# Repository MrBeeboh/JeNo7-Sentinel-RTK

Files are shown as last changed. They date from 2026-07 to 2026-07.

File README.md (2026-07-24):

# JeNo 7" + Sentinel RTK (work in progress)

Open packaging work to run an **F450 Sentinel–class RTK / ArduPilot / Walksnail** avionics stack on a **[JeNo 7"](https://github.com/WE-are-FPV/JeNo-7)** long-range FPV frame.

This repo is **not** a finished airframe release. It is shared so others can reuse the **editable CAD pack**, the **Sentinel-on-JeNo layout plan**, and contribute mounts (GNSS roof, Walksnail dual plates, TPU).

---

## What’s in here

| Path | Contents |
|---|---|
| **`Sentinel-on-JeNo7/`** | Design plan: how Sentinel gear maps onto JeNo (UM980, Q39, Walksnail dual, LR900, RP3, stack) |
| **`Editable/`** | Split CAD for FreeCAD / Fusion / AutoCAD LT — one part per file where possible |
| **`JeNo-7-main/`** | Upstream JeNo 7" v1.1.1 sources (frame DXF/STEP/STL + official TPU) |

### Editable CAD pack (start here for redesign)

- `Editable/01-CARBON-3D/` — individual plate/arm **STEP** + **FCStd** (Fusion / FreeCAD)
- `Editable/02-CARBON-2D-DXF/` — per-plate **DXF** for CNC / AutoCAD LT (English layers: CUT, POCKET, …)
- `Editable/00-MASTER/` — full assembly STEP from the official export
- `Editable/README.md` — which tool opens what
- `Editable/FREECAD-HOWTO.md` — FreeCAD notes (imported solids are not parametric history)

### Sentinel packaging plan

- `Sentinel-on-JeNo7/DESIGN.md` — plain-language fit plan, what stock JeNo covers, what must be redesigned (GNSS roof, camera plates, sensors, 7" motors)

---

## License and attribution

### Upstream JeNo 7"

Frame and official TPU files in `JeNo-7-main/` are **[CC BY 4.0](https://creativecommons.org/licenses/by/4.0/)** by **WE are FPV / JeNo** (nochamo and community).  

Upstream project: [github.com/WE-are-FPV/JeNo-7](https://github.com/WE-are-FPV/JeNo-7)

If you redistribute or remix JeNo geometry, **credit WE are FPV / JeNo** and keep the license notice.

### This repository’s additions

Layout docs, split CAD packaging scripts, and Sentinel integration notes are provided for the community. When in doubt, treat remixes of JeNo geometry as still under **CC BY 4.0** with attribution to the original authors.

---

## Not included (on purpose)

- `JeNo-7-main.zip` — duplicate of the extracted tree  
- `Editable/03-TPU-3D/from-STL-mesh/` — huge mesh-derived STEP files; use official STLs under `JeNo-7-main/02-TPU/` instead  

---

## Related projects

- **JeNo 7" upstream:** https://github.com/WE-are-FPV/JeNo-7  
- **F450 Sentinel** (avionics / RTK source of truth for this build) lives in the builder’s local `F450-Sentinel` tree and is not fully mirrored here yet  

---

## Status

| Item | Status |
|---|---|
| Official JeNo files | Vendored v1.1.1 |
| Split editable CAD | Done (carbon + DXF + partial TPU solids) |
| Sentinel-on-JeNo design plan | Draft in `Sentinel-on-JeNo7/DESIGN.md` |
| GNSS roof plate CAD | **Not designed yet** |
| Walksnail dual camera plates | **Not designed yet** |
| Built / flown 7" Sentinel | **Not yet** |

Contributions welcome: roof plate DXF/STEP, Walksnail dual plates, TPU mounts, BOM for 7" motors/props with this stack.

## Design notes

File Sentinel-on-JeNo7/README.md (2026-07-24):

# Sentinel on JeNo 7"

Goal: fly the **F450 Sentinel** avionics and RTK mission on a **JeNo 7"** frame.

**Start here:** [DESIGN.md](DESIGN.md)

## Design files

| File | Type | What |
|---|---|---|
| `GNSS_Roof_Plate.scad` | OpenSCAD source | GNSS roof plate (parametrized) |
| `GNSS_Roof_Plate_fc.dxf` | DXF | **Use this for CNC cutting** — 14 circle holes + polyline outline |

**Note on OpenSCAD exports:** This system has OpenSCAD 2021.01 which has a buggy binary STL writer. Always use `--export-format asciistl` when exporting STL from the .scad files. The FreeCAD-generated files (`_fc.*`) are the production reference.
| `GNSS_Roof_Plate_fc.step` | STEP | 3D solid for Fusion/FreeCAD |
| `GNSS_Roof_Plate_fc.stl` | STL | 3D print for test fit |
| `TPU_Mounts.scad` | OpenSCAD source | Parametric LR900/RP3/CV50 mounts |
| `LR900_Mount.stl` | STL | TPU cradle for MicoAir LR900-P |
| `RP3_Mount.stl` | STL | TPU cradle for RadioMaster RP3 V2 |
| `CV50_Mount.stl` | STL | Nadir bracket for CV50 rangefinder |

## Related paths

- Frame CAD pack: `../JeNo-7-main/01-FRAME/`
- Official JeNo files: `../JeNo-7-main/`
- Sentinel electronics source of truth:  
  `../../F450-Sentinel/Current design folder/`

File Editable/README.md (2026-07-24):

# JeNo 7" — Editable CAD pack

Converted from the official open-source **JeNo 7 v1.1.1** export so you can open **one part at a time** in FreeCAD, Fusion 360, or AutoCAD LT.

**License:** CC BY 4.0 (credit WE are FPV / JeNo authors).  
**Source:** `../JeNo-7-main/` (unchanged originals).

---

## Which tool should I use?

| Goal | Best tool | Open these |
|---|---|---|
| Edit a carbon plate 3D (holes, outline, thickness) | **Fusion** or **FreeCAD** | `01-CARBON-3D/*.step` |
| Send carbon to CNC / edit 2D cut paths | **AutoCAD LT** (or Fusion sketch) | `02-CARBON-2D-DXF/` |
| Edit TPU print parts | **FreeCAD** or **Fusion** | `03-TPU-3D/from-assembly-STEP/` first; full kit in `from-STL-mesh/` |
| Print TPU as-is (no edit) | Slicer | original `../JeNo-7-main/02-TPU/*.stl` |
| See whole assembled frame | FreeCAD / Fusion | `00-MASTER/JeNo7_Assembly_from_STEP.step` |

**Recommended workflow for most changes**

1. **Fusion (other PC):** File → Open → pick a single `01-CARBON-3D/*.step`  
2. Right‑click body → **Convert** / work in **Parametric** design (or capture design history if offered)  
3. Edit, then export STEP (for FreeCAD) and DXF (for CNC)  

or

1. **FreeCAD:** File → Open → `01-CARBON-3D/Bottom_plate_3mm.FCStd` (or `.step`)  
2. Use **Part Design** / **Part** to cut holes, pad, boolean  
3. Export STEP / TechDraw DXF when done  

or

1. **AutoCAD LT:** open a file under `02-CARBON-2D-DXF/from-all-versions-dxf/`  
2. Layers: `CUT`, `POCKET`, `CHAMFER`, `COUNTERSINK`  
3. Edit polylines → save DXF for the CNC shop  

---

## Folder map

```
Editable/
├── README.md                          ← this file
├── 00-MASTER/
│   ├── JeNo7_Assembly_from_STEP.step  ← full assembly (one config)
│   ├── JeNo7_Assembly_from_STEP.FCStd
│   └── PARTS_MANIFEST.txt
├── 01-CARBON-3D/                      ← BEST for Fusion + FreeCAD
│   ├── Arm_8mm.step / .FCStd
│   ├── Arm_key.step / .FCStd
│   ├── Bottom_plate_3mm.step / .FCStd
│   ├── Middle_plate_2p5mm.step / .FCStd
│   ├── Top_plate_2p5mm.step / .FCStd
│   └── Camera_plate_25deg_O4.step / .FCStd
├── 02-CARBON-2D-DXF/
│   ├── from-all-versions-dxf/         ← BEST for AutoCAD LT (all options)
│   │   ├── 00_ALL_VERSIONS_English_layers.dxf
│   │   ├── Bottom_plate_variant_*.dxf
│   │   ├── Top_plate_variant_*.dxf
│   │   ├── Middle_plate_variant_*.dxf
│   │   ├── Camera_plate_variant_*.dxf
│   │   ├── Arm_or_reinforcement_*.dxf
│   │   └── PART_INDEX.txt
│   └── from-step-projection/          ← 2D of the STEP config only
├── 03-TPU-3D/                         ← TPU / print parts
│   ├── from-assembly-STEP/            ← cleaner BREP solids (prefer for edit)
│   └── from-STL-mesh/                 ← full kit from official STLs (heavy meshes)
├── 04-HARDWARE-REF/                   ← standoff reference solids
└── scripts/                           ← re-run converters if needed
```

---

## Important limitations (so you don’t fight the tools)

1. **These are not parametric native Fusion/SolidWorks projects.**  
   They are **BREP solids** (STEP) and **2D polylines** (DXF) reverse-exported from the official cut files. You can edit them freely, but there is **no design history** (no sketch tree from the original author).

2. **The STEP assembly is one configuration only**  
   (8 mm arms + top/bottom “04” + 25° O4 camera plates + some TPU).  
   **All carbon options** (Classic/Light/Bando, 6 mm arms, other cam plates) live in the **DXF pack** under `from-all-versions-dxf/`.

3. **TPU from STLs** (`JeNo7_*.step`) can be heavy mesh-based solids. Prefer:
   - `TPU_Rear_bumper.step`, `TPU_Antenna_*.step` from the assembly when present  
   - or re-model from the STL as a size reference  

4. **CC BY 4.0:** if you publish a remix, credit JeNo / WE are FPV.

---

## Quick start by app

### Fusion 360 (Windows PC)

1. Copy `01-CARBON-3D/` (and optionally `03-TPU-3D/TPU_*.step`) to the other PC.  
2. **Insert → Insert Mesh** is **not** what you want. Use **File → Open** on the `.step`.  
3. If Fusion asks to capture design history: **yes** if you want timeline features.  
4. For CNC: create a sketch from the face → **DXF export**, or use the ready DXFs in `02-CARBON-2D-DXF/`.

### FreeCAD (this machine)

AppImage: `~/Applications/FreeCAD_1.1.1-Linux-x86_64-py311.AppImage`

```text
File → Open → Editable/01-CARBON-3D/Bottom_plate_3mm.FCStd
```

Or open the assembly:

```text
Editable/00-MASTER/JeNo7_Assembly_from_STEP.FCStd
```

Each body is a separate `Part::Feature` you can toggle visible and edit.

### AutoCAD LT

Open either:

- **One plate:** `02-CARBON-2D-DXF/from-all-versions-dxf/Bottom_plate_variant_01.dxf`  
- **Whole sheet, English layers:** `00_ALL_VERSIONS_English_layers.dxf`

Layer meanings:

| Layer | Meaning |
|---|---|
| `CUT` | Outer profile / through cuts |
| `POCKET` | Pockets (partial depth) |
| `CHAMFER` | Chamfers |
| `COUNTERSINK` | Countersinks |
| `ANNOTATION` | Labels (not cut) |

See `PART_INDEX.txt` for sizes of each split plate.

---

## Re-generate this pack

If you update the upstream JeNo zip:

```bash
# 1) Split STEP → per-part STEP/FCStd (FreeCAD)
~/Applications/FreeCAD_1.1.1-Linux-x86_64-py311.AppImage -c \
  "import runpy; runpy.run_path(r'.../Editable/scripts/01_split_step_to_parts.py', run_name='__main__')"

# 2) Split ALL_VERSIONS DXF for ACAD LT
python3 ".../Editable/scripts/02_split_dxf_all_versions.py"

# 3) Project carbon STEP → DXF
~/Applications/FreeCAD_1.1.1-Linux-x86_64-py311.AppImage -c \
  "import runpy; runpy.run_path(r'.../Editable/scripts/03_project_carbon_to_dxf.py', run_name='__main__')"
```

---

## What to open first (suggested)

| If you want to… | Open |
|---|---|
| Lengthen the body / move stack holes | `01-CARBON-3D/Bottom_plate_3mm.step` + `Middle_plate_2p5mm.step` + `Top_plate_2p5mm.step` |
| Change motor spacing | `01-CARBON-3D/Arm_8mm.step` |
| Change camera angle / O3 vs O4 plate | DXF `Camera_plate_variant_*.dxf` (all options) or STEP `Camera_plate_25deg_O4.step` |
| Print TPU bumper | `03-TPU-3D/TPU_Rear_bumper.step` or `JeNo7_Back_Bumper.step` |

Original untouched sources remain in `../JeNo-7-main/`.

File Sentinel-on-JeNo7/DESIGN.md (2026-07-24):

# Sentinel on JeNo 7" — Design plan

**What this is:** A plan to move the **F450 Sentinel electronics and mission** (RTK rover, Walksnail dual, ArduPilot stack, radios) onto a **JeNo 7"** carbon frame, and to list what must be redesigned so you can reshape plates and mounts freely later.

**What this is not:** A finished CAD package yet. You asked to modify parts so everything fits — this document is the map of *what* has to change and *where* each Sentinel piece goes, so CAD work has a target instead of guesswork.

**Source of truth for electronics:**  
`Documents/DRONE Builds/F450-Sentinel/Current design folder/`  
especially `README.md`, `Stack_and_Wiring.md`, `ArduPilot_Configuration.md`.

**Source of truth for frame geometry:**  
`Documents/DRONE Builds/custom 7 inch frame/Editable/`  
and official `JeNo-7-main/`.

---

## 1. Goal in one paragraph

You want one aircraft that flies as a **7" long-range / freeride FPV platform** (JeNo) but carries the **Sentinel payload**: ArduPilot H743 stack, Walksnail Avatar HD Pro Dual, UM980 + Waveshare Q39 helix, UBEC for the GNSS, LR900 telemetry (RTCM path), RP3 ELRS, and the optical flow / rangefinder path you already run on the F450. The ground base station (second UM980 + LicheeRV Nano) stays on the ground — it does not move onto the airframe.

---

## 2. Assumptions (top three)

If any of these is wrong, say so and we adjust the plan.

1. **You are transplanting the Sentinel *avionics and wiring philosophy*, not the F450 airframe as a whole.** The F450’s 10" props and A2212 motors do **not** bolt onto JeNo 7" arms. The 7" needs its own motors and props (typically 2806–3008 class, 16–19 mm mount, 7" props).  
2. **Firmware and serial map stay Sentinel-style** (H743, Avatar on the O3/HD VTX plug as SERIAL2, UM980 on GPS/SERIAL3, LR900 on telemetry, RP3 on ELRS). Frame changes do not change that map.  
3. **Base station stays ground-side.** Only the **rover** UM980 + Q39 fly on the JeNo.

---

## 3. Why the stock JeNo is not enough by itself

The JeNo 7" is a **clean FPV frame**: one compact body (~30 mm tall inside), Wide-X arms, camera plates aimed at DJI O3/O4 or Walksnail, room for a 30×30 stack, battery straps on the bottom plate. It was **not** designed as a multi-layer “pagoda” RTK ship like the F450 Sentinel.

On the F450 you solved space by stacking plates:

- Battery under the bottom  
- Avatar VTX on a lower deck  
- FC/ESC higher up  
- Roof plate with Q39 + UM980 and UBEC under the roof  

On the JeNo you only have about **30 mm of body height** between bottom and top carbon, plus whatever you hang outside (TPU, antenna masts, a small roof add-on). So “fit everything” means **re-packing** Sentinel gear into a flatter layout, and **cutting or printing** a few custom pieces — not dropping the F450 pagoda unchanged onto a 7".

That is the real design problem. It is mechanical packaging, not a FreeCAD mystery.

---

## 4. What already fits stock JeNo (little or no carbon change)

| Sentinel item | Size / need | Stock JeNo support |
|---|---|---|
| AERO SELFIE H743 + 45A 4-in-1 | 30.5×30.5 mm stack | **Yes** — main stack pattern is 30×30 M3 |
| Battery (strap) | Underslung | **Yes** — bottom plate has strap slots |
| Walksnail Avatar camera | FPV cam forward | **Mostly** — use Walksnail-friendly camera plates / soft mount; JeNo is O3/O4-first but README lists Walksnail as supported VTX class |
| Walksnail VTX board | ~33.5 mm class, heat, 9V | **Yes with placement care** — rear / bottom bay or soft mount; not as spacious as F450 L1 deck |
| RP3 V2 ELRS | 22×13 mm + two antennas | **Yes** — TPU / zip / arm; keep antennas away from Q39 and LR900 |
| LR900-P | ~43×26×11 mm + 915 MHz whip | **Yes** — rear bay or arm; **≥200 mm** from RP3 antennas (same rule as F450) |
| UBEC | Small | **Yes** — under top plate or beside stack, clear of Q39 |
| Wiring philosophy | UBEC → UM980 only; ESC BAT for pack | **Unchanged** — does not depend on F450 plates |

So the FC stack, radios, and power tree can live on JeNo **if** you decide placement and print a few TPU pieces. The hard parts are **GNSS roof**, **Walksnail dual packaging**, and **nadir sensor view**.

---

## 5. What does *not* fit as a simple “drop in”

### 5.1 UM980 + Waveshare Q39 (must redesign mount)

- **UM980 carrier:** about **26 × 38 × 7.6 mm**  
- **Q39 helix:** tall multi-band antenna that needs **clear sky**, nothing metal above it, short SMA run to the UM980  

On F450 these live on a dedicated **roof plate (L4)** with the UBEC on the underside. Stock JeNo **top plate** is only about **58 × 195 × 2.5 mm** and is already the lid of a tight FPV body. You cannot honestly park a Q39 “wherever” next to props and carbon and expect good RTK.

**You need one of these (pick later in CAD):**

- **A)** A small **add-on GNSS roof plate** (new carbon or thick G10) on standoffs above the JeNo top plate, with:  
  - flat pad for UM980 (M2/M3 or VHB pattern)  
  - Q39 mount (SMA bulkhead or antenna base footprint)  
  - hole for short coax  
  - optional UBEC pads on the **underside** of that roof (same idea as Sentinel)  
- **B)** A tall **TPU mast** on the rear/top that holds Q39 high and the UM980 just below it, still with sky view  

**Recommendation:** Option **A** — closest to what already works on Sentinel, easiest to keep RF clean, and you can design that one plate in Fusion as a freeform part.

### 5.2 Walksnail Avatar HD Pro Dual

- **Camera** wants a solid forward mount and tilt (your choice of angle).  
- **VTX** wants airflow and 9V from the FC HD/VTX path (same as today: O3 Air Unit plug = Avatar = SERIAL2).  
- Dual antenna paths need TPU SMA mounts (JeNo already has SMA TPU options; may need remix for dual Walksnail antennas).

Stock **O3/O4 camera plates** are not the same as a dual Avatar camera cage. Plan on either:

- community Walksnail plate for JeNo 7, or  
- **custom camera plates** (3 mm carbon) sized to the Avatar dual camera module.

### 5.3 Optical flow / rangefinder (MTF-01 and/or CV50)

Your current Ardu docs lean on **MTF-01** on SERIAL4; build sheet history also has **CV50** nadir. Whichever you fly:

- Needs a **clear view straight down** (or as designed for that sensor).  
- On F450 that was an underside mount on a transverse deck.  
- On JeNo, bottom plate is busy with battery strap and arms. Typical approach: **rear or side cutout / small printed bracket** under the middle/bottom plate so the sensor sees ground between the battery and the props.

This is a **new small part** (TPU or 2.5 mm plate tab), not a stock JeNo feature.

### 5.4 Motors and props (new purchase, not a frame hole problem)

| F450 Sentinel | JeNo 7" |
|---|---|
| A2212-class, **10"** props | **7"** props, 16–19 mm motor pattern on arms |
| Larger, slower cruise setup | Faster / different disc loading |

**Do not plan to reuse the 10" prop/motor set on JeNo arms.** Budget new 7" motors/props (and retune Ardu later). Frame CAD work is separate from that shopping list.

---

## 6. Proposed layout on JeNo (target packaging)

Think in layers again, but flatter than the F450 pagoda.

```
                    [ Q39 helix ]     clear sky
                    [ UM980  ]       short SMA
                 ── GNSS roof plate (NEW) ──
                         │ short standoffs
                 ── JeNo top plate ──
                    UBEC underside or side
                    FC + ESC 30.5 stack (center)
                    LR900 / RP3 (sides or rear, antennas split)
                 ── middle / body volume ──
                    Avatar VTX (rear or side bay, airflow)
                 ── JeNo bottom plate ──
                    battery strap underslung
                    flow/lidar looking down (clear FOV)
        ── camera plates ──  Avatar dual camera forward
        ── 8 mm arms ──  7" motors (new)
```

### Placement rules carried over from Sentinel (still valid)

- Q39: nothing above it; short coax to UM980.  
- UBEC: not directly under the helix if you can avoid it; if it is under the roof, verify sat quality before you call the layout final.  
- LR900 915 MHz whip and RP3 2.4 GHz antennas: **at least ~200 mm apart**, opposite corners of the frame if possible.  
- Avatar 5.8 GHz antennas: clear of battery and big carbon walls; not tied in the same zip as GNSS coax.  
- UM980 UART cable: twisted, away from ESC battery leads and VTX coax.  
- UM980 power: **only from UBEC**, not from the FC GPS 5V pin (same hard rule as F450).

---

## 7. What to redesign in CAD (your “do whatever I want” list)

These are the **editable pieces** that make the transplant real. Prefer **Fusion** on your other PC with STEP/DXF from `Editable/`. FreeCAD is optional, not required.

| Priority | Part | Base file to start from | What you change |
|---|---|---|---|
| **P0** | **GNSS roof plate** (new) | Blank from dimensions, or top plate as size reference | Outline, standoff holes matching JeNo top, UM980 holes, Q39 base, wire pass-through |
| **P0** | **Camera plates for Avatar dual** | `Camera_plate_*` DXF/STEP or new from dual cam dimensions | Hole pattern and tilt for Walksnail dual, not O3 |
| **P1** | **Top plate** (optional mods) | `Top_plate_2p5mm.step` | Extra holes for roof standoffs, antenna bulkheads, cable exits |
| **P1** | **Bottom plate** (optional mods) | `Bottom_plate_3mm.step` | Sensor window / bracket holes; keep strap slots |
| **P1** | **TPU set** | Official JeNo TPU + new prints | Dual SMA for Walksnail, LR900 clip, RP3 mount, Q39 mast if no carbon roof, CV50/MTF-01 pod |
| **P2** | Middle plate | `Middle_plate_2p5mm.step` | Only if stack height or routing needs a cutout |
| **P2** | Arms | Stock 8 mm | Usually leave alone; motor holes already 16–19 mm |

**You do not need to redesign the entire ALL_VERSIONS DXF on day one.** Start with **GNSS roof + camera plates + TPU**. The stock bottom/middle/arms can stay JeNo 8 mm until something physically does not fit.

---

## 8. Electronics that stay the same (no frame math)

Copy from Sentinel as-is unless you choose to change:

- H743 + 45A ESC, ArduPilot params (motor class will need retune later)  
- Avatar on **O3 Air Unit plug** → SERIAL2 / DisplayPort (do not re-argue this)  
- UM980 on GPS plug → SERIAL3, `GPS1_TYPE=24`  
- LR900 on telemetry path for MAVLink + RTCM inject  
- RP3 on ELRS plug  
- UBEC 5V only to UM980  
- Base station on the ground  

When the airframe is 7" with new motors, you will retune rates and battery failsafe for the new AUW — that is flight testing, not carbon day one.

---

## 9. Suggested build sequence (so nothing is wasted)

1. **Decide layout on paper** using this doc (roof vs mast for Q39; where LR900/RP3 sit).  
2. **CAD the GNSS roof plate** in Fusion from scratch (simplest high-value part). Export DXF for cut + STEP for your records.  
3. **CAD or buy Walksnail dual camera plates** for JeNo width.  
4. **Print TPU** antenna and sensor brackets; dry-fit on a naked JeNo or printed dummy.  
5. **Order 8 mm JeNo carbon** (stock or your modified DXFs) + **7" motors/props**.  
6. **Wire like Sentinel** (same harness rules, re-measure lengths for the shorter stack).  
7. **Bench:** RTK Fixed with UBEC on, Avatar video, ELRS, LR900, no props.  
8. **Hover / tune** for 7" AUW.

---

## 10. What I will not pretend

- Stock JeNo files are **not** a ready “Sentinel edition.” They are a good FPV base that we **extend**.  
- FreeCAD fighting you does not mean the project is impossible; it means **use Fusion for freeform plate redesign**, and use DXF for the CNC shop.  
- Fitting UM980 + Q39 **without** a roof or mast is how you get a pretty drone that will not hold RTK. That mount is non-negotiable.

---

## 11. Next concrete step

When you are ready to move from planning to metal:

**Design the GNSS roof plate first** — outline, four standoff holes that match the JeNo top plate pattern, UM980 footprint (26×38 mm carrier), Q39 mount, and a small cable hole. That single part unlocks the whole Sentinel mission on this frame.

Say if you want that plate’s dimensions worked out next (hole coordinates from the top plate STEP), and whether you prefer **carbon roof on standoffs** or a **tall rear TPU mast**. That choice drives every other antenna placement.

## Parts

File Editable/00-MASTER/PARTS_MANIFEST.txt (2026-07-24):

JeNo 7 editable parts (generated from official STEP export)
Source: JeNo7_ALL_VERSIONS_1.1.1.step

Part                                     Cat        DXF
------------------------------------------------------------
Arm_8mm                                  carbon     no
Arm_key                                  carbon     no
Bottom_plate_3mm                         carbon     no
Camera_plate_25deg_O4                    carbon     no
Middle_plate_2p5mm                       carbon     no
Standoff_M3x20                           hardware   no
Standoff_M3x30                           hardware   no
TPU_Antenna_O3                           tpu        no
TPU_Antenna_support                      tpu        no
TPU_Capacitor_support_35Vx2              tpu        no
TPU_Rear_bumper                          tpu        no
Top_plate_2p5mm                          carbon     no

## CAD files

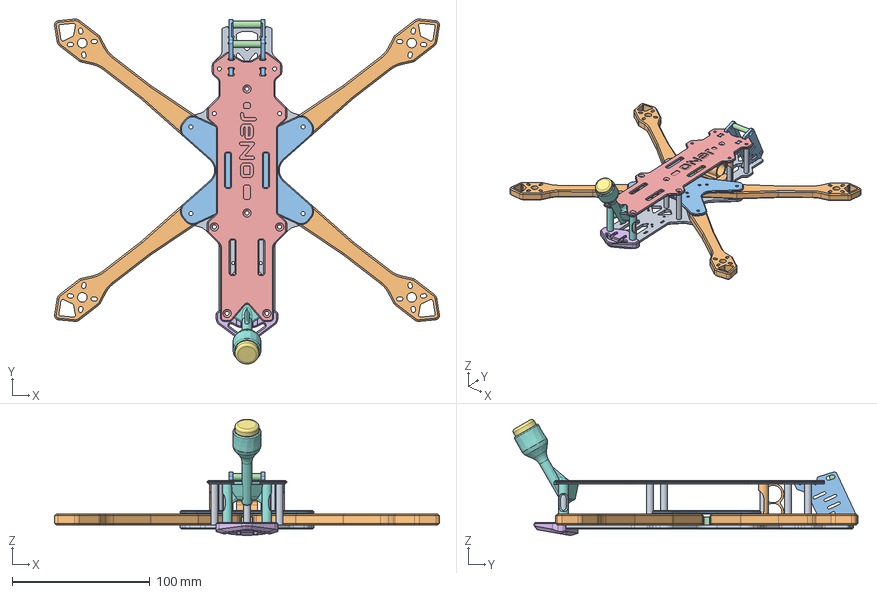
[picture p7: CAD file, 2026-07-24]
Editable/00-MASTER/JeNo7_Assembly_from_STEP.step
279.6 x 250.5 x 84.4 mm
Standoff_M3x30
Standoff_M3x30 (instance 1)
Standoff_M3x30 (instance 2)
Standoff_M3x30 (instance 3)
Standoff_M3x30 (instance 4)
Standoff_M3x30 (instance 5)
Standoff_M3x30 (instance 6)
Standoff_M3x30 (instance 7)
Standoff_M3x30 (instance 8)
Standoff_M3x30 (instance 9)
Arm_8mm
Middle_plate_2p5mm
Arm_key
Top_plate_2p5mm
TPU_Rear_bumper
TPU_Antenna_O3
TPU_Antenna_support
Bottom_plate_3mm
Arm_8mm (instance 18)
Arm_8mm (instance 19)
Arm_8mm (instance 20)
TPU_Capacitor_support_35Vx2
Bottom_plate_3mm (instance 22)
Camera_plate_25deg_O4
Standoff_M3x20
Standoff_M3x20 (instance 25)
Camera_plate_25deg_O4 (instance 26)

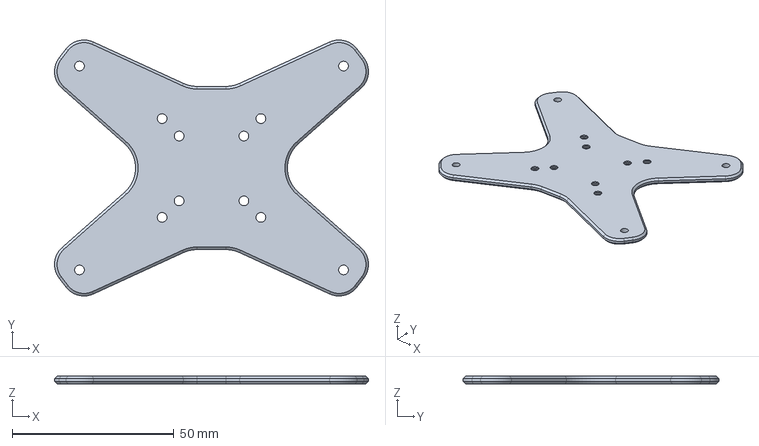
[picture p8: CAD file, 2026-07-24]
Editable/01-CARBON-3D/Middle_plate_2p5mm_EditReady.FCStd
96.9 x 79.0 x 2.50 mm

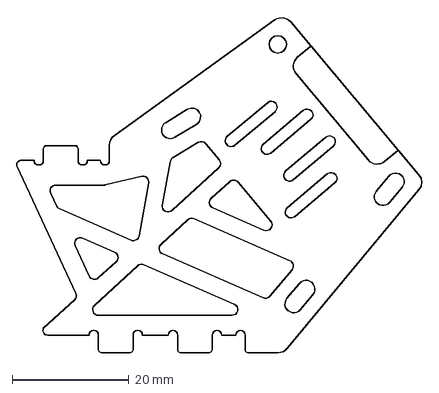
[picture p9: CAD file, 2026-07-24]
Editable/02-CARBON-2D-DXF/from-all-versions-dxf/Camera_plate_variant_16.dxf
69.7 x 57.7 mm

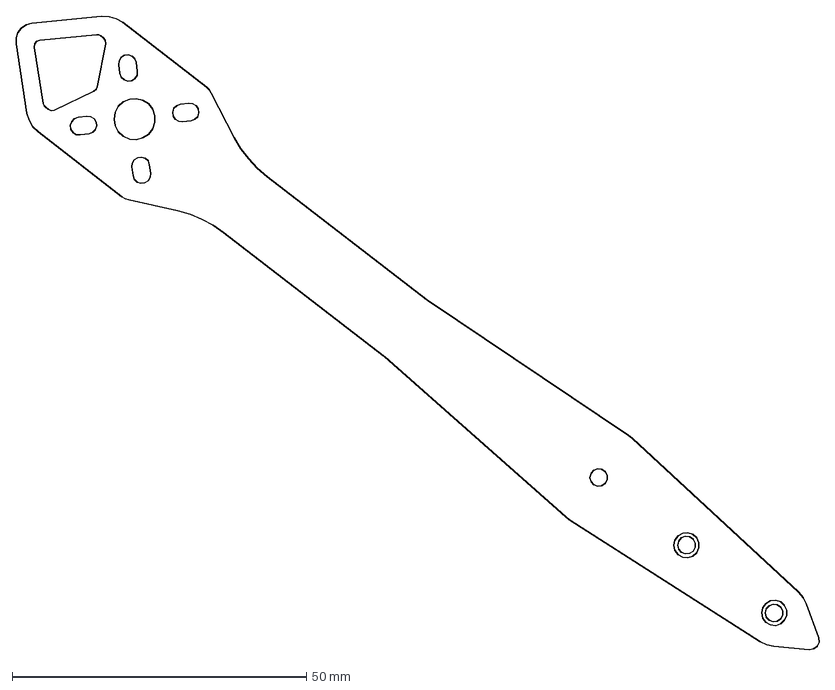
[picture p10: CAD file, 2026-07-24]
Editable/02-CARBON-2D-DXF/from-step-projection/Arm_8mm.dxf
136.4 x 107.5 mm

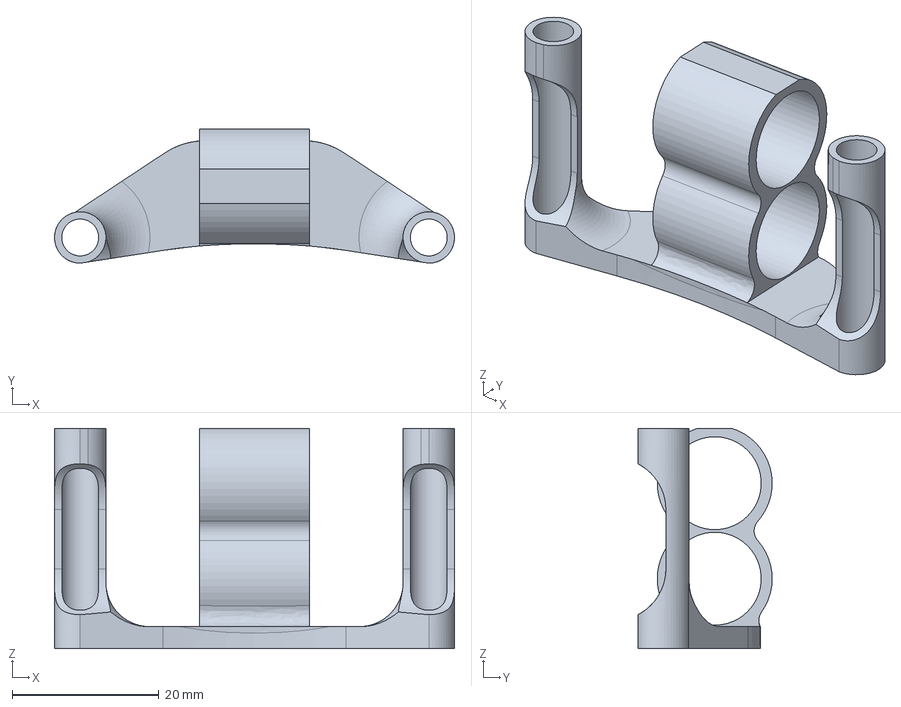
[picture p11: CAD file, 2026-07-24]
Editable/03-TPU-3D/from-assembly-STEP/TPU_Capacitor_support_35Vx2.step
54.5 x 18.3 x 30.0 mm

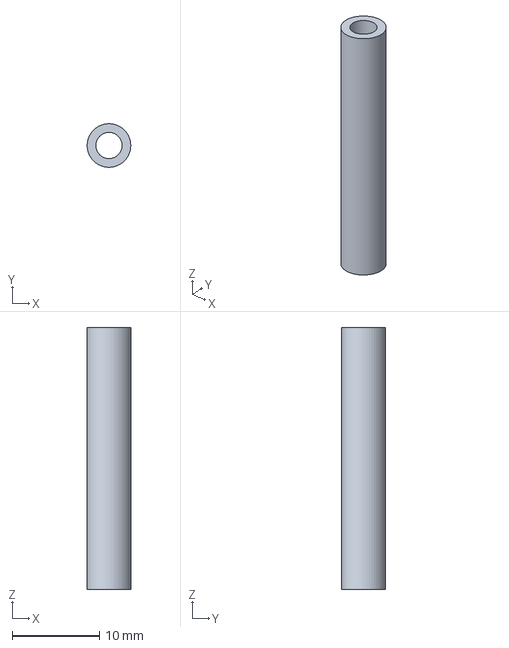
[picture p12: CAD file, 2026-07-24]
Editable/04-HARDWARE-REF/Standoff_M3x30.step
5.00 x 5.00 x 30.0 mm

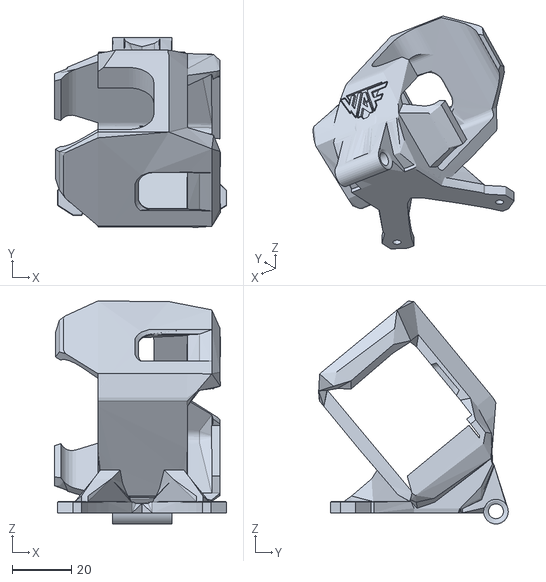
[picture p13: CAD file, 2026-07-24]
JeNo-7-main/04-TPU-HISTORY/JeNo7_1.0.0_Gopro_Mini_40deg.stl
58.0 x 63.8 x 75.0

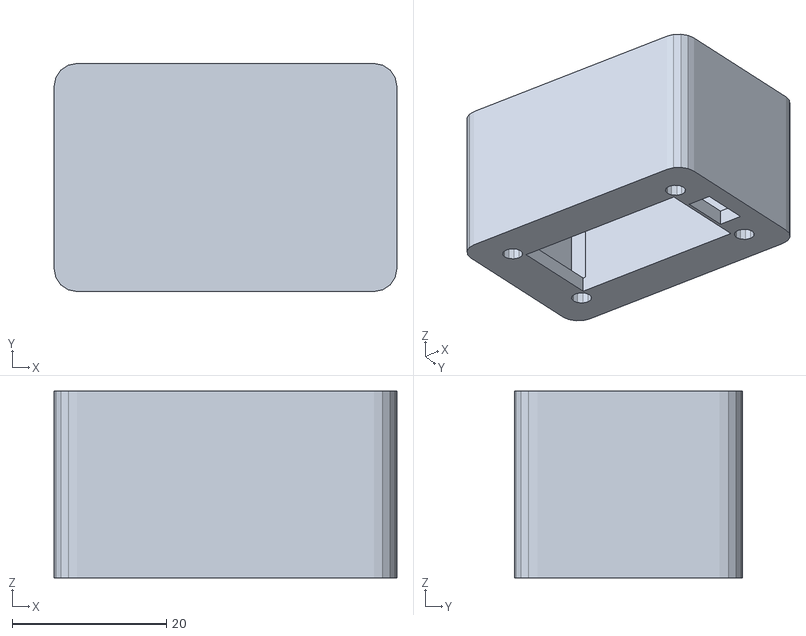
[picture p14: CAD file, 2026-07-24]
Sentinel-on-JeNo7/CV50_Mount.stl
44.5 x 29.6 x 24.2

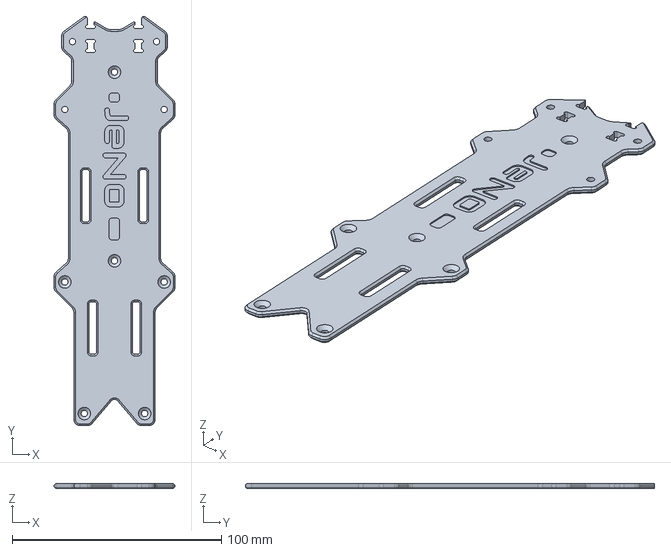
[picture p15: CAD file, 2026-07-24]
Editable/01-CARBON-3D/Top_plate_2p5mm.step
57.8 x 195.4 x 2.50 mm

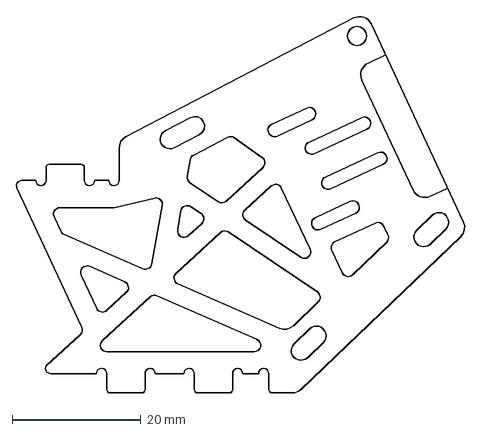
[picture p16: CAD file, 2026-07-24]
Editable/02-CARBON-2D-DXF/from-all-versions-dxf/Camera_plate_variant_12.dxf
69.8 x 58.5 mm

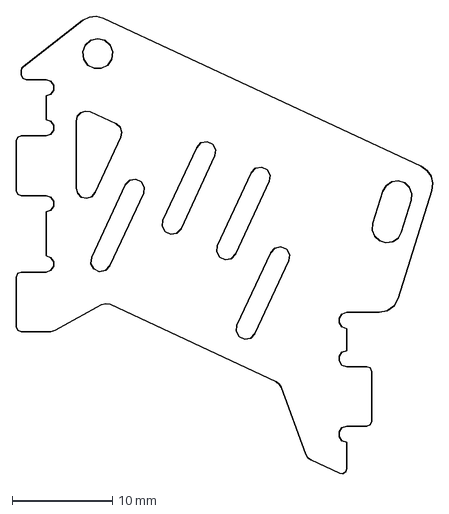
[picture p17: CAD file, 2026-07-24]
Editable/02-CARBON-2D-DXF/from-step-projection/Camera_plate_25deg_O4.dxf
41.6 x 45.7 mm

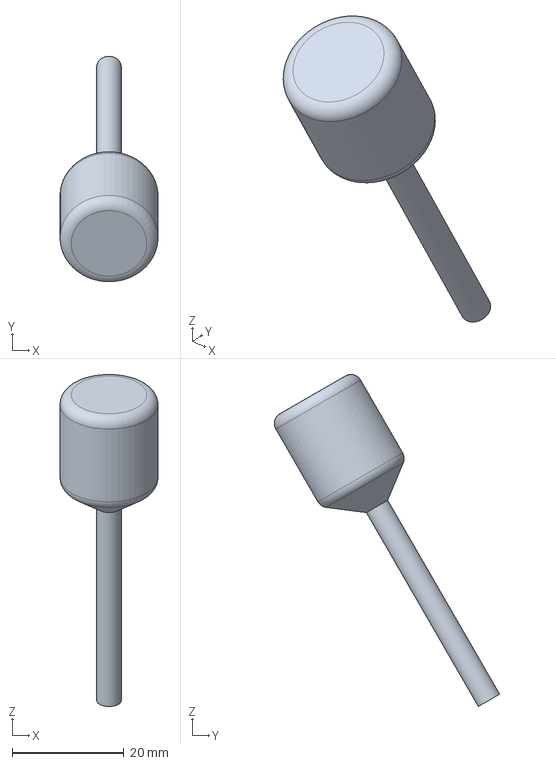
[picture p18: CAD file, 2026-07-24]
Editable/03-TPU-3D/from-assembly-STEP/TPU_Antenna_O3.step
17.5 x 40.2 x 59.3 mm

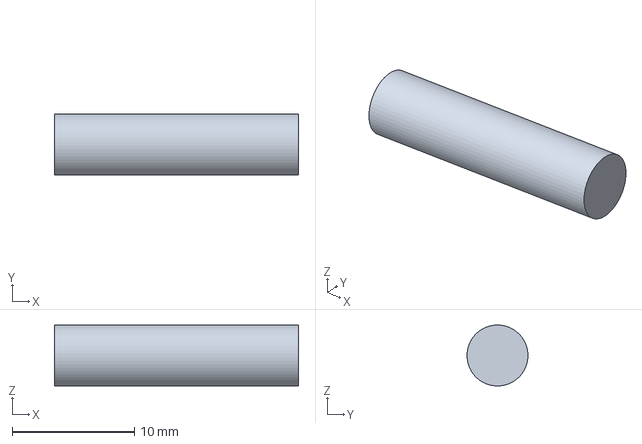
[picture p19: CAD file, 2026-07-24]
Editable/04-HARDWARE-REF/Standoff_M3x20.step
20.0 x 5.00 x 5.00 mm

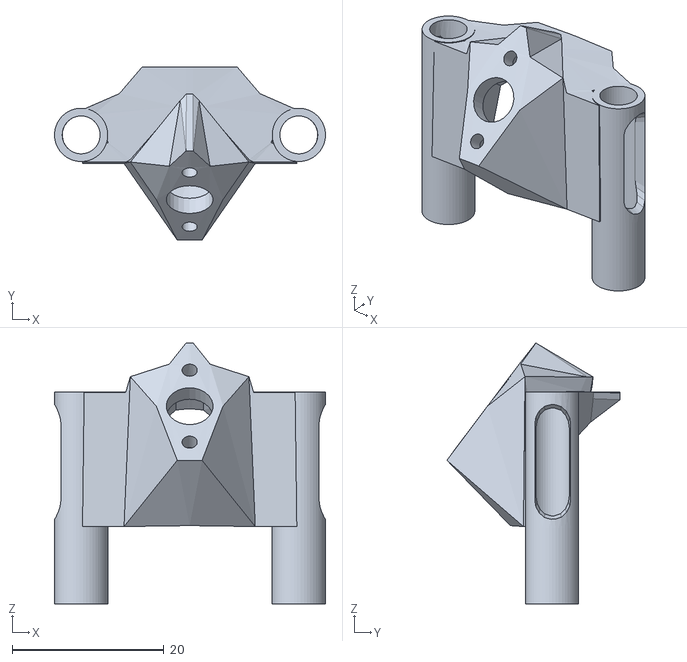
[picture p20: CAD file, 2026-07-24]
JeNo-7-main/02-TPU/JeNo7_Antenna_SMA.stl
35.7 x 22.8 x 34.4

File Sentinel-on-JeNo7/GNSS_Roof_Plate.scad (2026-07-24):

// GNSS Roof Plate — JeNo 7" Sentinel RTK Build
// ==============================================
// A forward-cantilevered carbon roof plate that mounts on M3 standoffs
// above the JeNo 7 top plate. Carries the UM980 + Q39 helix forward of
// the battery so pack swaps stay unobstructed.
//
// Output modes:
//   3D model (default)    → export STL for visualization
//   export_2d = true      → export DXF for carbon cutting
//
// Example:
//   openscad -o GNSS_Roof_Plate.stl --export-format asciistl GNSS_Roof_Plate.scad
//   openscad -o GNSS_Roof_Plate.dxf -D 'export_2d=true' GNSS_Roof_Plate.scad
//
// NOTE: OpenSCAD 2021 binary STL writer is buggy on this system.
// Always use --export-format asciistl for STL output.
// The FreeCAD-generated files (GNSS_Roof_Plate_fc.*) are the
// production reference — use GNSS_Roof_Plate_fc.dxf for CNC.
//
// Coordinate system: matches JeNo 7 STEP file
//   X+ = right, Y+ = forward, Z+ = up
//   Top plate Z = 30.0–32.5mm

// ============================================================
// PARAMETERS — edit these to fit your hardware
// ============================================================

plate_thickness   = 2.5;   // [2, 2.5, 3] mm carbon plate
standoff_height   = 20;    // mm from JeNo top plate top face
screw_dia_m3      = 3.2;   // M3 clearance hole
screw_dia_m2_5    = 2.8;   // M2.5 clearance hole

// ============================================================
// STANDOFF MOUNTING — JENO 7 TOP PLATE HOLE PATTERN
// ============================================================

// These are the existing holes on the JeNo 7 top plate (Z=32.5mm).
// The roof plate uses M3 male-female standoffs screwed into these.
standoff_positions = [
    [ 20.08,  73.58],   // front right
    [-20.08,  73.58],   // front left
    [ 23.73,  41.18],   // rear right
    [-23.73,  41.18],   // rear left
];

// ============================================================
// GNSS PAYLOAD
// ============================================================

// UM980 carrier board: ~26x38mm, M2.5 on ~20x32mm pattern
um980_center   = [0, 76];
um980_mount_xy = [20, 30];           // M2.5 hole spacing (x, y)
um980_screw    = screw_dia_m2_5;

// Q39 helix antenna: 48mm dia, M3 on 38mm square
q39_center     = [0, 86];
q39_diameter   = 48;
q39_mount      = 38;                  // square spacing
q39_screw      = screw_dia_m3;
sma_hole       = 7.0;                 // SMA pass-through at Q39 center

// Cable pass-through for UM980 UART + power
cable_hole_pos = [0, 68];
cable_hole_dia = 9.0;

// UBEC — FPVKing Micro UBEC 5V/3A mounted on plate underside
// ~20×15×6mm body, zip-tie or VHB
ubec_center    = [0, 55];
ubec_size      = [20, 15, 6];

// Anti-rotation pin holes for zip-ties securing the UBEC
ubec_strap_slots = [
    [-16, 55], [16, 55]
];

// ============================================================
// PLATE OUTLINE (top-down polyline, Z=0 plane)
// ============================================================

// Matches the JeNo top plate profile in the mounting region,
// flares ~4mm wider at the GNSS section for payload clearance,
// then tapers to a rounded nose forward of the camera.
//
// The battery on the main top plate (roughly Y=-40 to Y=+55)
// is completely unobstructed — this roof only covers Y=37 to Y=94.

plate_outline = [
    // — rear edge (flat) —
    [-28, 37], [28, 37],
    // — right side, going forward —
    [28, 44],
    [27, 55],                        // matches top plate waist
    [28, 65],
    [30, 74],                        // flare starts near front standoffs
    [32, 78],
    [32, 86],                        // widest — Q39 fits with 8mm margin
    [31, 92],
    [26, 96],
    [0,  98],                         // rounded nose
    // — left side, coming back —
    [-26, 96],
    [-31, 92],
    [-32, 86],
    [-32, 78],
    [-30, 74],
    [-28, 65],
    [-27, 55],
    [-28, 44],
];

// ============================================================
// RENDER SWITCH
// ============================================================

export_2d = false;   // set true for DXF export

// ============================================================
// MODULES
// ============================================================

module main_shape_2d() {
    // Plate body with 3mm corner fillets
    offset(r = 3) polygon(plate_outline);
}

module standoff_holes_2d() {
    for (p = standoff_positions)
        translate(p) circle(d = screw_dia_m3, $fn = 24);
}

module um980_holes_2d() {
    for (x = [-1, 1], y = [-1, 1])
        translate([
            um980_center[0] + x * um980_mount_xy[0] / 2,
            um980_center[1] + y * um980_mount_xy[1] / 2
        ]) circle(d = um980_screw, $fn = 16);
}

module q39_holes_2d() {
    for (x = [-1, 1], y = [-1, 1])
        translate([
            q39_center[0] + x * q39_mount / 2,
            q39_center[1] + y * q39_mount / 2
        ]) circle(d = q39_screw, $fn = 24);
    // SMA pass-through at Q39 center
    translate(q39_center) circle(d = sma_hole, $fn = 24);
}

module cable_hole_2d() {
    translate(cable_hole_pos) circle(d = cable_hole_dia, $fn = 24);
}

module ubec_strap_slots_2d() {
    // Small slots for zip-ties securing the UBEC on the underside
    for (p = ubec_strap_slots)
        translate(p)
            square([3, 8], center = true);
}

module all_holes_2d() {
    standoff_holes_2d();
    um980_holes_2d();
    q39_holes_2d();
    cable_hole_2d();
    ubec_strap_slots_2d();
}

// ============================================================
// OUTPUT
// ============================================================

if (export_2d) {
    // 2D profile for DXF export (carbon cutter)
    difference() {
        main_shape_2d();
        all_holes_2d();
    }
} else {
    // 3D model for STL export (visualization / test print)
    color("DimGray") linear_extrude(height = plate_thickness, convexity = 10)
        difference() {
            main_shape_2d();
            all_holes_2d();
        }

    // Show the UM980 carrier as a translucent reference
    %translate([um980_center[0], um980_center[1], plate_thickness])
        color("RoyalBlue", 0.3)
            cube([26, 38, 1.6], center = true);

    // Show the Q39 helix as a translucent reference
    %translate([q39_center[0], q39_center[1], plate_thickness])
        color("MediumSeaGreen", 0.25)
            cylinder(d = q39_diameter, h = 10, $fn = 48);

    // Show standoff columns as reference
    for (p = standoff_positions) {
        %translate([p[0], p[1], -standoff_height])
            color("Silver", 0.3)
                cylinder(d = 5, h = standoff_height, $fn = 16);
    }

    // Show the UBEC on the underside as a translucent reference
    %translate([ubec_center[0], ubec_center[1], -6])
        color("Goldenrod", 0.25)
            cube([ubec_size[0], ubec_size[1], ubec_size[2]], center = true);
}

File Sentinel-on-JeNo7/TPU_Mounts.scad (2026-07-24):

// TPU Mounts — LR900-P, RP3 V2, CV50 — JeNo 7" Sentinel RTK
// ============================================================
// Three separate TPU mounting brackets.
//
// Select one: PART = "LR900", "RP3", or "CV50"
//
// All build as a single solid block with cavities carved out
// of the top — always manifold-safe.
//
// Examples:
//   openscad -o LR900_Mount.stl -D 'PART="LR900"' TPU_Mounts.scad
//   openscad -o RP3_Mount.stl   -D 'PART="RP3"'   TPU_Mounts.scad
//   openscad -o CV50_Mount.stl  -D 'PART="CV50"'  TPU_Mounts.scad
// ============================================================

PART = "LR900"; // "LR900", "RP3", "CV50", "ALL"

// ============================================================
// COMMON PARAMETERS
// ============================================================
wall = 2.0;     // wall thickness
base = 1.8;     // thickness of material under the device
m3_d = 3.2;     // M3 clearance
m2_d = 2.2;     // M2 clearance
zip = 3.0;      // zip-tie slot width

// ============================================================
// LR900-P — 915 MHz LoRa Telemetry Module
// ============================================================
// Dimensions: 43.4 × 25.8 × 11 mm (body)
// Mount: SMA whip on one end, UART header on side
// Can be zip-tied to arm or screwed to plate

module lr900_mount() {
    dx = 43.4;  // device length (X)
    dy = 25.8;  // device width (Y)
    dz = 11.0;  // device height

    ox = dx + 8;   // outer X
    oy = dy + 8;   // outer Y
    oz = dz + 2;   // total Z (base + cavity height)

    // SMA end extends 4mm beyond the end — make room
    sx = 4;  // extra on SMA end

    difference() {
        // — SOLID BLOCK —
        linear_extrude(height = oz, convexity = 4)
            offset(r = 3)
                square([ox, oy], center = true);

        // — DEVICE POCKET (carved from top, base remains) —
        translate([0, 0, oz - dz - 0.1])
            linear_extrude(height = dz + 0.2, convexity = 4)
                square([dx + 0.5, dy + 0.5], center = true);

        // — CABLE RELIEF (UART side) —
        translate([dx/2 + wall - 1, 0, base + 1])
            cube([4, 6, dz - 2], center = true);

        // — ZIP-TIE SLOTS (long axis) —
        for (x = [-1, 1])
            translate([x * 10, 0, 0])
                linear_extrude(height = oz + 1, convexity = 2)
                    square([zip, oy + 2], center = true);

        // — M3 MOUNT HOLES (through base) —
        for (x = [-1, 1], y = [-1, 1])
            translate([x * (ox/2 - 3), y * (oy/2 - 3), -0.5])
                cylinder(d = m3_d, h = base + 1, $fn = 12);
    }
}

// ============================================================
// RP3 V2 — ELRS Receiver
// ============================================================
// Dimensions: 22 × 13 × 4 mm
// Dual 65 mm 2.4 GHz antennas via IPEX

module rp3_mount() {
    dx = 22;
    dy = 13;
    dz = 4;

    ox = dx + 8;
    oy = dy + 8;
    oz = dz + 2;

    difference() {
        // — SOLID BLOCK —
        linear_extrude(height = oz, convexity = 4)
            offset(r = 3)
                square([ox, oy], center = true);

        // — DEVICE POCKET —
        translate([1, 0, oz - dz - 0.1])
            linear_extrude(height = dz + 0.2, convexity = 4)
                square([dx, dy + 0.5], center = true);

        // — ANTENNA CABLE NOTCH (rear) —
        translate([-ox/2 - 1, 0, base + 2])
            cube([4, 5, dz - 1], center = true);

        // — ZIP-TIE SLOT —
        translate([0, 0, -0.5])
            linear_extrude(height = oz + 1, convexity = 2)
                square([ox + 1, zip], center = true);

        // — M3 MOUNT HOLES —
        for (x = [-1, 1], y = [-1, 1])
            translate([x * (ox/2 - 3), y * (oy/2 - 3), -0.5])
                cylinder(d = m3_d, h = base + 1, $fn = 12);
    }
}

// ============================================================
// CV50 — 50m dToF Rangefinder
// ============================================================
// Dimensions: 28.5 × 13.6 × 21.4 mm
// Lens points down (-Z), ribbon exits one end
// Mounts under bottom plate, nadir view must be clear

module cv50_mount() {
    dx = 28.5;
    dy = 13.6;
    dz = 21.4;

    // Mounting margin
    mx = dx + 10;
    my = dy + 10;

    // Total height: base + device depth
    oz = base + dz + 1;

    difference() {
        // — SOLID BLOCK (mounts to frame top, device hangs down) —
        linear_extrude(height = oz, convexity = 4)
            offset(r = 3)
                square([mx, my], center = true);

        // — DEVICE POCKET (carved from bottom up) —
        // The device sits inside the block, lens near the bottom
        translate([0, 0, -0.1])
            linear_extrude(height = oz - base + 0.1, convexity = 4)
                square([dx + 1, dy + 1], center = true);

        // — LENS WINDOW (clear viewing aperture, bottom face) —
        translate([0, 0, -0.5])
            linear_extrude(height = base + 1, convexity = 2)
                circle(d = 12, $fn = 24);

        // — RIBBON EXIT SLOT (one narrow end) —
        translate([mx/2 - 2, 0, base + 2])
            cube([4, 8, dz - 3], center = true);

        // — M3 MOUNT HOLES (top plate, through base) —
        for (x = [-1, 1], y = [-1, 1])
            translate([x * (mx/2 - 3), y * (my/2 - 3), -0.5])
                cylinder(d = m3_d, h = base + 1, $fn = 12);

        // — WEIGHT REDUCTION (sides of the tall block) —
        for (x = [-1, 1])
            translate([x * (mx/2 - 3), 0, oz/2])
                cube([4, my - 6, oz - base - 3], center = true);
    }
}

// ============================================================
// RENDER
// ============================================================
$fn = 16;

if (PART == "LR900") {
    lr900_mount();
} else if (PART == "RP3") {
    rp3_mount();
} else if (PART == "CV50") {
    cv50_mount();
} else if (PART == "ALL") {
    translate([-35, 0, 0]) lr900_mount();
    translate([ 35, 0, 0]) rp3_mount();
    translate([  0, -35, 0]) cv50_mount();
}

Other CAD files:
JeNo-7-main/01-FRAME/JeNo7_ALL_VERSIONS_1.1.1.step
JeNo-7-main/02-TPU/JeNo7_Capacitor_Support_35Vx2.stl
JeNo-7-main/03-FRAME-HISTORY/JeNo7_ALL_VERSIONS_1.0.0.dxf
JeNo-7-main/04-TPU-HISTORY/JeNo7_1.0.0_Session_High_Tilt.stl
Editable/00-MASTER/JeNo7_Assembly_from_STEP.FCStd
Editable/01-CARBON-3D/Arm_8mm.FCStd
Editable/01-CARBON-3D/Arm_8mm.step
Editable/01-CARBON-3D/Arm_8mm_EditReady.FCStd
Editable/01-CARBON-3D/Arm_key.FCStd
Editable/01-CARBON-3D/Arm_key.step
Editable/01-CARBON-3D/Arm_key_EditReady.FCStd
Editable/01-CARBON-3D/Bottom_plate_3mm.FCStd
Editable/01-CARBON-3D/Bottom_plate_3mm.step
Editable/01-CARBON-3D/Bottom_plate_3mm_EditReady.FCStd
Editable/01-CARBON-3D/Camera_plate_25deg_O4.FCStd
Editable/01-CARBON-3D/Camera_plate_25deg_O4.step
Editable/01-CARBON-3D/Camera_plate_25deg_O4_EditReady.FCStd
Editable/01-CARBON-3D/Middle_plate_2p5mm.FCStd
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

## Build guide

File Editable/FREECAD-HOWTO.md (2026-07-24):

# FreeCAD how-to: JeNo carbon plates

You’re not doing anything wrong. The plate is a **finished solid** (imported STEP), not a sketch with dimensions. FreeCAD lets you **select** it, but it will **not** act like Fusion’s parametric timeline until you use the right tools.

Open this file (easiest start):

```text
Editable/01-CARBON-3D/Bottom_plate_3mm_EditReady.FCStd
```

(or the plain `Bottom_plate_3mm.FCStd` — measuring works on both)

---

## 1) Measure distance between two holes

### Method A — Measure tool (FreeCAD 1.0 / 1.1)

1. Switch workbench: **Part** or **Part Design** (top dropdown).
2. Menu: **Tools → Measure**  
   (or toolbar: ruler / “Measure” icon — looks like a measuring tape).
3. In the Measure panel, choose **Distance** (or **Linear distance**).
4. Click **first** hole edge (or the circle edge of the hole).
5. Click **second** hole edge.
6. Read the distance in the panel / on-screen.

**Tips**

- Zoom in so you click the **circular edge** of the hole, not a random face.
- If it measures face-to-face oddly, click **vertex** (corner points on the circle) or use Method B.
- Units are **mm** for these files.

### Method B — Two centers via Draft (very reliable)

1. Workbench: **Draft**.
2. Select the bottom plate solid in the tree (left).
3. Menu: **Draft → Utils → Shape 2D view** is optional; often skip.
4. Easier: Workbench **Part** → select a **circular hole edge** (one click on the circle).
5. Look at the bottom status / **Combo View → Model → Data** — or use:

**Part → Measure → Linear length** (older builds) / **Tools → Measure**.

### Method C — Python console (always works)

1. Menu: **View → Panels → Python console**.
2. Select **hole edge 1** (one circular edge), note it, or run after selecting two edges:

```python
# Select TWO circular edges (Ctrl+click), then run:
import FreeCAD as App
import FreeCADGui as Gui
sel = Gui.Selection.getSelectionEx()[0]
e1, e2 = sel.SubObjects[0], sel.SubObjects[1]
c1 = e1.Curve.Center
c2 = e2.Curve.Center
d = c1.distanceToPoint(c2)
print(f"Center-to-center: {d:.3f} mm")
print(f"  hole1 center: ({c1.x:.3f}, {c1.y:.3f}, {c1.z:.3f})")
print(f"  hole2 center: ({c2.x:.3f}, {c2.y:.3f}, {c2.z:.3f})")
```

That’s the **true hole spacing** CNC cares about.

### Method D — Bounding box of whole plate

```python
s = App.ActiveDocument.ActiveObject.Shape  # or get by name
print(s.BoundBox.XLength, s.BoundBox.YLength, s.BoundBox.ZLength)
```

Bottom plate should be about **97 × 217 × 3 mm**.

---

## 2) Why you “can’t do anything” with it

| What you expect (Fusion-style) | What this file is |
|---|---|
| Drag a dimension, holes move | **No history** — solid only |
| Double-click sketch | There is **no sketch** yet |
| Edit feature tree | Only one solid: `Part::Feature` or `BaseFeature` |

So: **selecting ≠ editing**. You must **add** features (sketch + pocket, or boolean cut).

---

## 3) How to actually modify the plate

### A) Cut a new hole (Part Design) — recommended

1. Open `Bottom_plate_3mm_EditReady.FCStd`.
2. Workbench: **Part Design**.
3. In the tree, **double-click `Body`** (active body is bold/highlighted).
4. Click the **large flat face** of the plate (the top surface).
5. Toolbar: **Create sketch**.
6. Draw a **circle** where you want a hole.
7. Close sketch (right-click → Close / same sketch icon).
8. **Pocket** → type Through all (or 3 mm).
9. You now have an editable feature in the tree.

### B) Boolean cut (Part workbench) — simple

1. Workbench: **Part**.
2. Create a cylinder: **Part → Primitives → Cylinder** (radius = hole, height = 10 mm).
3. Place it through the plate (Placement in Data tab: Position X/Y/Z).
4. Select **plate**, then **Ctrl+select cylinder**.
5. **Part → Boolean → Cut**.

### C) Don’t fight FreeCAD — use AutoCAD LT for 2D hole moves

If you only need to move holes for CNC:

1. Open  
   `Editable/02-CARBON-2D-DXF/from-all-versions-dxf/Bottom_plate_variant_01.dxf`  
   in **AutoCAD LT**.
2. Move circles / polylines.
3. Save DXF → send to CNC.

That’s often faster than FreeCAD for pure 2D carbon.

### D) Fusion (other PC) — often easiest for “edit solid”

1. Copy `Bottom_plate_3mm.step` to the Fusion PC.
2. **File → Open** the STEP.
3. **Create → Create Sketch** on the face → project geometry / draw holes → extrude cut.
4. Or **Modify → Press Pull** on faces/holes where it allows.

---

## 4) Selection tips in FreeCAD

| Want to select… | How |
|---|-----|
| Whole solid | Click in **tree** (left), not the 3D view |
| One face | Click face once; hover shows face |
| Hole circle | Zoom in, click the **edge** of the hole |
| Second object | **Ctrl+click** |
| Clear selection | Click empty space |

Tree icons:

- **Solid / ImportedSolid** — fine for measure + Part boolean  
- **Body → BaseFeature** — use this path for **Sketch / Pocket**  

---

## 5) Common “it won’t let me” fixes

1. **Sketch icon greyed out**  
   - Activate **Body** (double-click it).  
   - Select a **flat face** first.  
   - Must be on **Part Design** workbench.

2. **Measure does nothing**  
   - Need **two** selections (two edges/vertices).  
   - Or use Python method C above.

3. **Can’t drag the solid**  
   - Imported solids don’t “drag dimensions.”  
   - Change **Placement** in **Data** tab (X/Y/Z) only moves the whole part.

4. **Everything is tiny or huge**  
   - Scroll middle mouse to zoom; these parts are ~200 mm — if the view is empty, press **V then F** (view fit / fit all) or click **Fit all** in the view toolbar.

5. **Accidental “Transform” mode**  
   - Press **Esc** or right-click → clear transform.

---

## 6) Quick checklist for “measure two motor holes”

1. Open `Bottom_plate_3mm_EditReady.FCStd`  
2. **V then F** (fit all)  
3. Zoom to two holes  
4. **Tools → Measure → Distance**  
5. Click circle edge 1, circle edge 2  
6. Or: select two edges → paste Method C in Python console  

---

## 7) If you want Fusion-like editing long term

Best path for big redesigns:

1. Edit in **Fusion** from the `.step`, **or**  
2. Rebuild critical holes as a **new sketch** on the face in FreeCAD Part Design, then pocket — leave the import as BaseFeature.

You’re not blocked by a lock; FreeCAD is just treating this as a **brick of geometry** until you add sketches/features on top.

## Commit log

2026-07-24 Initial public release: JeNo 7 editable CAD pack and Sentinel-on-JeNo plan
    Include upstream JeNo 7 v1.1.1 (CC BY 4.0, WE are FPV), split STEP/DXF/FCStd
    parts for Fusion/FreeCAD/AutoCAD LT, and a design plan for packaging the
    F450 Sentinel RTK/Walksnail stack on the 7" frame.
    Exclude duplicate zip and oversized mesh-derived TPU STEP conversions.
    [00_ALL_VERSIONS_English_layers.dxf, Arm_8mm.FCStd, Arm_8mm.dxf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]
2026-07-24 Add GNSS roof plate, TPU mounts, and .gitignore
    GNSS roof plate (P0):
    - Forward-cantilevered 2.5mm carbon plate on 20mm standoffs
    - Uses 4 existing JeNo top plate holes — no frame mods
    - UM980 carrier + Q39 helix mount + SMA passthrough
    - UBEC underside mount with zip-tie slots
    - Battery on main top plate fully accessible (roof only covers Y=37-98)
    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
    [CV50_Mount.stl, GNSS_Roof_Plate.dxf, GNSS_Roof_Plate.scad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]
2026-07-24 Fix corrupted STLs — use manifold-safe geometry and ASCII STL export
    All three TPU mounts rewritten as single solid blocks with cavities
    carved from top — eliminates non-manifold geometry that caused
    CGAL to produce corrupted STL output.
    GNSS roof plate STL fixed — use --export-format asciistl for
    OpenSCAD export (binary STL writer is buggy on OpenSCAD 2021.01).
    Production reference files (FreeCAD-generated) were always correct:
    GNSS_Roof_Plate_fc.dxf, GNSS_Roof_Plate_fc.step, GNSS_Roof_Plate_fc.stl
    [CV50_Mount.stl, GNSS_Roof_Plate.scad, LR900_Mount.stl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]
